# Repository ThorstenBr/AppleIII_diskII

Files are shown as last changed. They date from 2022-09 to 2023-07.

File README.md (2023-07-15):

# Apple III to disk II / FloppyEmu Adapter
This project decribes how to build an adapter connecting an Apple III to a [FloppyEmu from Big Mess of Wires](https://www.bigmessowires.com/floppy-emu/) - an SD-card based disk drive emulator.
Alternatively, the adapter can also be used to connect the Apple III to an original Apple **Disk II** drive (yes, Disk II, not Disk III).
The adapter works with either the internal or external floppy port of the Apple III.

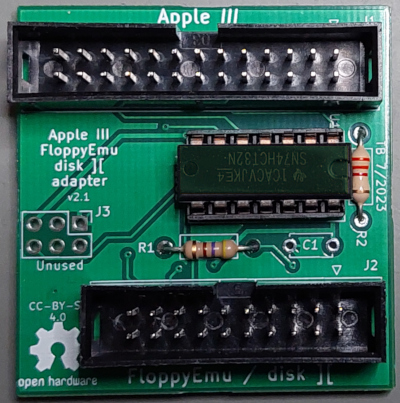
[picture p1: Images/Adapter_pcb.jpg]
Apple III FloppyEmu adapter PCB


As a bonus I also added a design file for a 3D-printed slim enclosure:

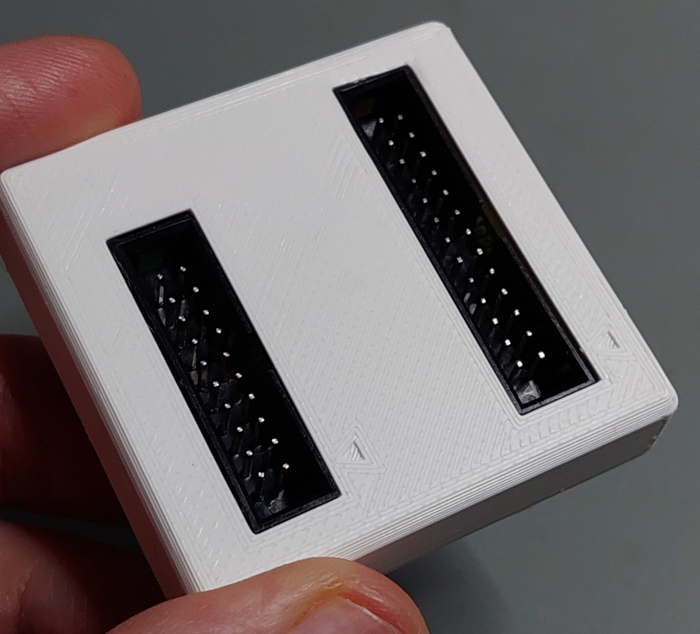
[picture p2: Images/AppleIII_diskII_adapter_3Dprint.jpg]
Apple III to Disk II adapter: 3D print


## License
This project is released under the "Creative Commons Attribution 4.0 International Public License". See [LICENSE](LICENSE).

## Description
It doesn't take much to connect a FloppyEmu to an Apple III. The disk drive interface of the Apple III is very similar to the Apple II - with most signals being completely identical. The Apple III, however, has a few extra signals and features, hence it uses a wider 26pin connector, instead of the 20pin connector of the Apple II. Most extra pins are not required for normal operation.

A few people have made the connection between Apple III and FloppyEmu/DiskII with a simple ribbon cable: using a 26pin IDC connector at one end, and a 20pin IDC connector (stripping the top 6 wires) at the other end. That did mostly work (if you don't mess up, reverse the connectors or strip wires from the wrong side, that is...). You can find more on this in [Steve's (BMOW) blog post](https://www.bigmessowires.com/2017/01/25/floppy-emu-on-the-apple-iii/).

**However**, such a simple 26pin to 20pin cable is not to be recommended - and it will not always work. For proper operation, one of the additional signals also has to be considered (see the "errata" section below, if you are interested in the details).

This adapter uses a cheap logic IC (74LS32) to properly decode the Apple /// drive enable signals and provide a signal to FloppyEmu or disk II. When connected to a FloppyEmu, the adapter also supports its "dual drive emulation" feature, where it emulates two separate disk drives.

The adapter can be connected to the Apple III disk port (internal or external port) and provides a standard 20pin connector, which can be used directly with the original FloppyEmu/Disk II cables.

### Using the Apple III external floppy port
You can connect the adapter to the external floppy port at the rear of your Apple III.

* **Disk II**: When using the external floppy port, the connected disk II drive acts as the system's "drive #2" (".D2", which confusingly is sometimes also refered to as "**external** drive #1").
* **FloppyEmu**: When connecting a FloppyEmu, you can enable its dual drive support. In this case your FloppyEmu will emulate the system "drive #2" and "drive #3" (".D2" and ".D3" - which are sometimes also called "**external** drives #1 and #2"). So, including the internal drive, you then have three floppy drives connected to your Apple III.

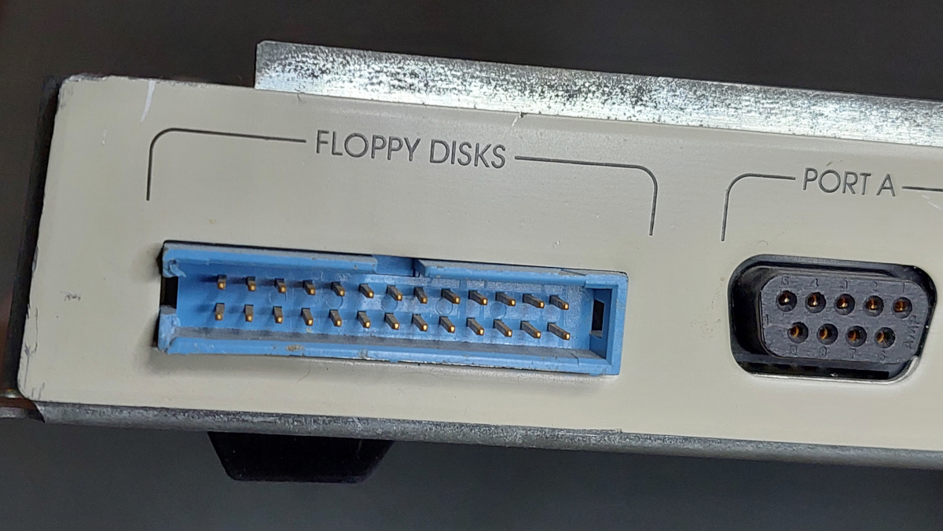
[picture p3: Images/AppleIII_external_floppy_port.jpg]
Apple III external floppy port


### Using the Apple III internal floppy port
The internal port connects the boot drive (system drive #1).
You can simply unplug the installed ribbon cable from the internal drive and plug it to the adapter's Apple III port.
No extra cable is required.

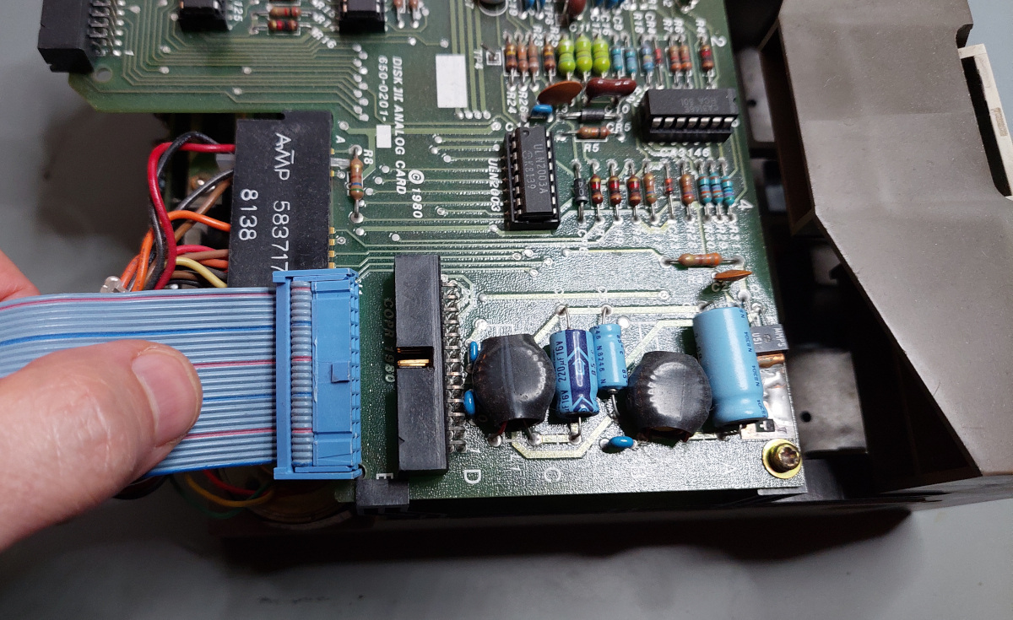
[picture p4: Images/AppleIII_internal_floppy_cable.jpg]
Apple III internal floppy cable

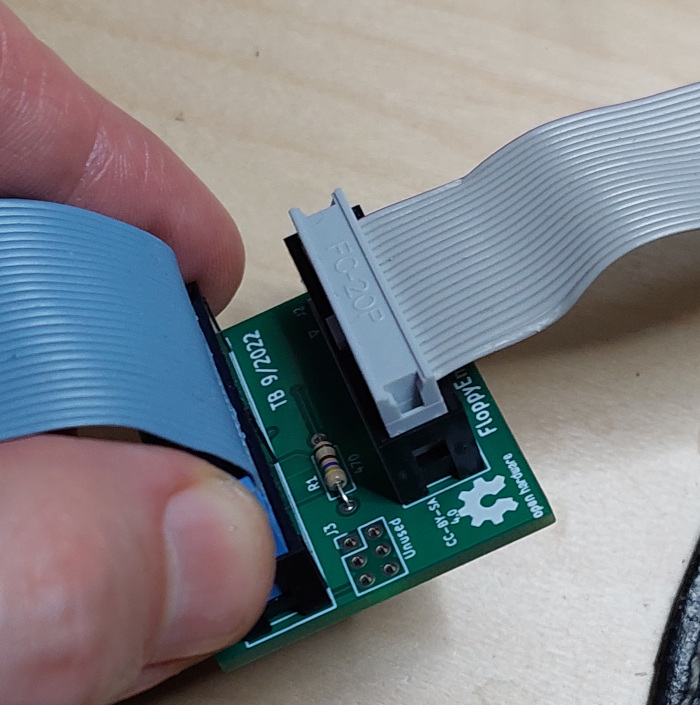
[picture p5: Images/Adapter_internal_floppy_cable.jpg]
Apple III internal floppy cable


When using the internal Apple III floppy port, the connected drive acts as drive #1 (".D1", boot drive).
The internal port does not support the signals for the external drives, however.
So, unfortunately you cannot make use of FloppyEmu's dual drive support to also emulate drive #2, when using the internal connector.

If you connect a new cable to the mainboard: the internal port is located on the mainboard right next to the external port:

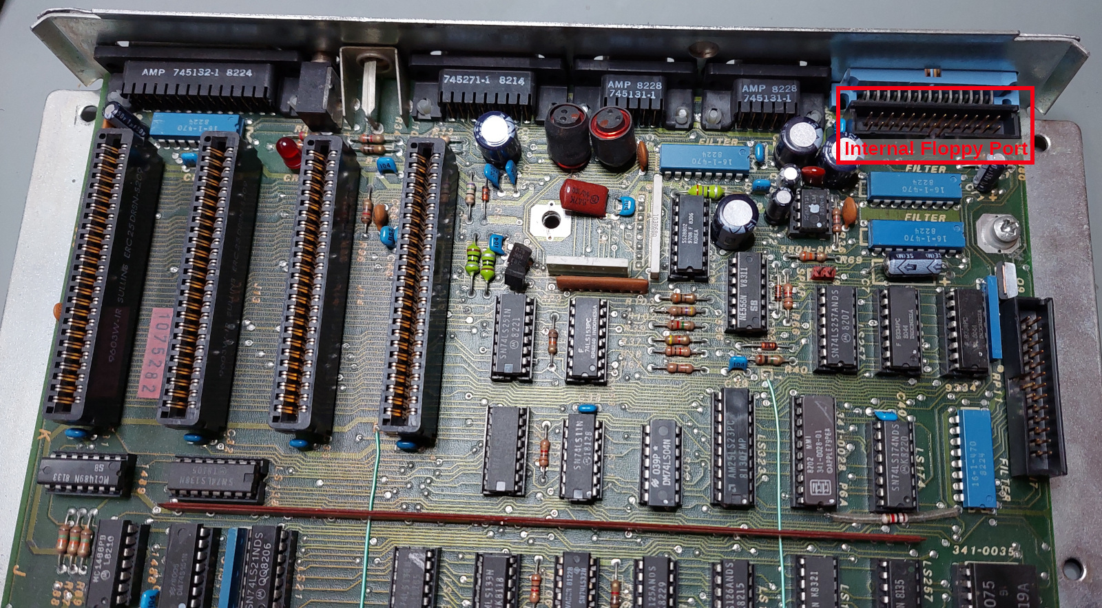
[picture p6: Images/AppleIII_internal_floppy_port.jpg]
Apple III internal floppy cable


## Parts List
Parts list for the completed PCB:
* 1x 20pin box header
* 1x 26pin box header
* 1x 14pin DIP socket (recommended)
* 1x IC SN74LS32 "OR-Gate" (74HCT32 also works but requires the optional 3K3 resistors)
* 1x 470 Ohm resistor
* 2x 3.3K Ohm resistors (optional/recommended)
* PCB (see Gerber files below)

<!--
![Adapter parts list](Images/Adapter_parts_list.jpg)
-->

Additionally, if you wanted to use Apple III's external floppy port, you may need a short 26pin ribbon cable with appropriate IDC sockets.
* 2x 26-pin IDC socket (with strain relief)
* 1x 26pin ribbon cable (a few inches/centimers are enough)

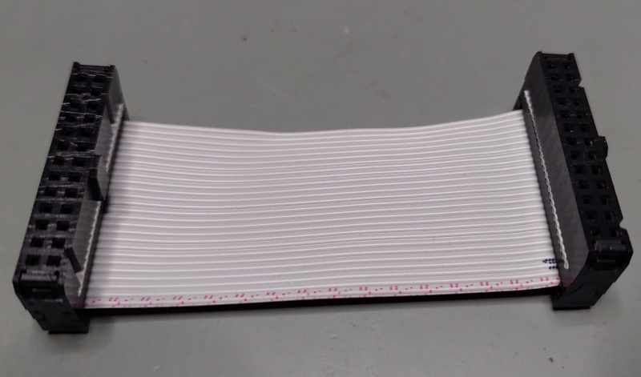
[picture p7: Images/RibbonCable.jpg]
Short 26wire ribbon cable


A very short ribbon cable will be enough for the external port (since your disk II/floppyEmu already comes with a long ribbon cable). Note, if you have any wider ribbon cables, you can easily reduce them to the appropriate wire count (so you would not need to shop an entire roll of new 26-write ribbon cable).

If you make your own ribbon cable: **MAKE SURE THE IDC SOCKETS ARE ORIENTED CONSISTENTLY!** Do not flip or reverse the orientation of the connectors (place them on the same side of the ribbon cable and with the notch facing the same direction).

For the internal floppy port you can reuse the existing floppy cable of your Apple III (unplug the internal floppy and plug the cable into the adapter instead).

I ordered parts from my usual German electronics online shop for less than a buck. Add a few bucks if you need a new ribbon cable ([Shopping List at Reichelt.de](https://www.reichelt.de/my/1980987?LANGUAGE=EN)).
I created a public shopping list containing all the parts. All parts are extremely common and will be available for a long time.

## Gerber Files, Ordering a PCB
If you wished to directly order a PCB (PCBWay, JLCPCB etc) you could use the latest Gerber files from the [Gerber](Gerber/) directory. Just upload the ZIP file to your preferred PCB manufacturer and order the PCB. My PCBs were manufactured by JLCPCB (using the cheapest options, I got mine already after about 1.5 weeks for a few bucks/Euros).

## Soldering
Soldering is straight forward. Only simple through-hole components are used. All part numbers and component values are marked directly on the PCB.

**DOUBLE-CHECK THE PROPER ORIENTATION OF THE BOX HEADERS!**  
The notch for the box headers are clearly marked on the PCB.
Incorrect orientation of the box headers for the Apple III or FloppyEmu port will damage or destroy your Apple III and FloppyEmu/disk II drive - or both...

The capacitor (C1) was added on the PCB as a backup. It is not required (leave the slot unused).

Completed PCB with orientation of the box headers

### Soldering Options
There are three solder jumpers on the bottom side of the adapter:

* **JP1**: connects the "drive 2" signal to the 20-pin connector. This signal enables dual drive support of FloppyEmu. This signal cannot be used when connecting an original Apple disk II drive, though. Setting this jumper will not damage anything when a disk II drive was connected, since there is also a resistor protecting the pin. But it adds unnecessary load. So, it's recommended to only close JP1 when you connect a FloppyEmu (and intend to use the dual drive support). Otherwise leave this jumper open.
* **JP2, JP3**: These jumpers connect -12V and +12V to the 20pin floppy header. These voltage supplies are required for the Apple disk II drive. But they are not required by FloppyEmu. It's recommended to leave these jumpers open if you intend to only connect a FloppyEmu. But they have to be closed when you wanted to connect an original disk II drive.

Jumpers on the Apple III disk II adapter

## Installation
Make sure the Apple III is switched off. **Do not connect the adapter, the Disk II, or Floppy Emu while your machine is powered!**

* Connect the adapter to the external floppy port at the rear of your Apple III (26pin ribbon cable required). Alternatively, connect it to the internal floppy port: pull the 26pin ribbon cable from the internal disk drive and plug it into the adapter.
* Finally connect the FloppyEmu's ribbon cable to the adapter. The FloppyEmu cable has a keyed connector (with a notch), so it should only fit in correct orientation.

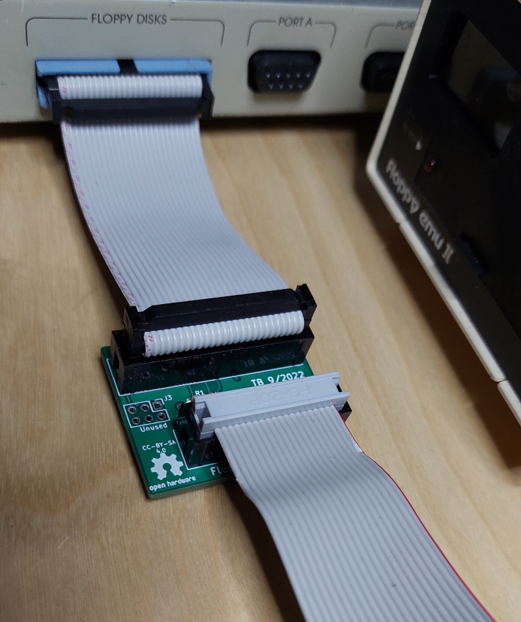
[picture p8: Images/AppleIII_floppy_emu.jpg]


* Alternatively, when you use the adapter to connect a Disk II drive, be extra careful: the Disk II connectors do not have a notch preventing incorrect orientation. You can easily plug them reversed, which will damage the drive and/or interface card. Pin 1 is marked with a little triangle on the PCB, on the 3D-printed enclosure - and also on the disk II connector.

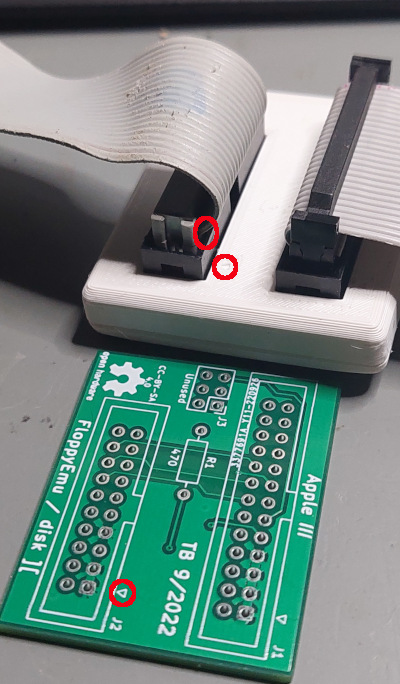
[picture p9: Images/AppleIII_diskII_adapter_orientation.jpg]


### Configuring the System for Three Drives

If you connect the FloppyEmu to the external connector, your system has three drives (the internal disk drive, and two external drives emulated by FloppyEmu).
However, with Apple's "SOS" operating system it is necessary to configure the system to make the third drive work (if your system was previously configured for two drives only).

Here are some hints on how to configure the Apple III:

* Use the "system utilities" disk.
* Enter the "System Configuration Program (SCP)".
* Select "Read a Driver File" to read ".D1/sos.driver" from your boot disk.
* Select "Change System Parameters".
* Set "Number of Disk III Drives" to 3 (or 4...).
* Select "Generate New System" and write the new configuration to ".D1/sos.driver" of your boot disk.

Yes, changing the configuration of the Apple III SOS is a bit inconvenient. :)
And make sure you have a backup of your boot disk, before you reconfigure anything...

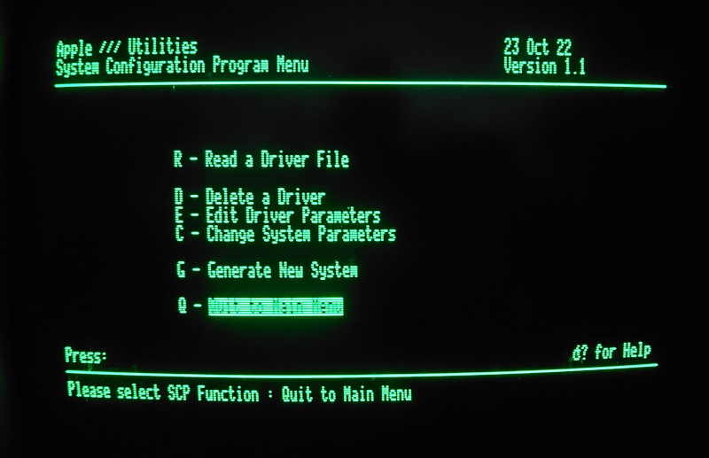
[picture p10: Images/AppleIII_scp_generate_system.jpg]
Apple SCP - generate new system


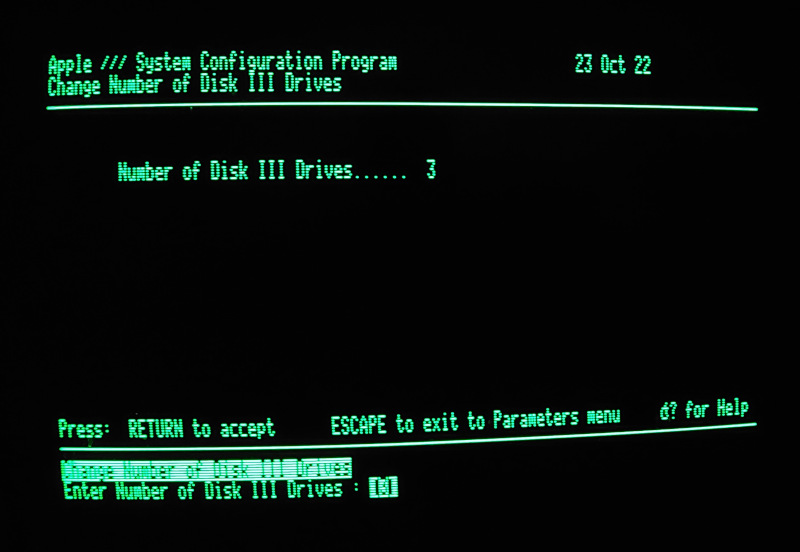
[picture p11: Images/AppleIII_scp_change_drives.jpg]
Apple SCP - change number of drives


## Errata / Technical Background ##
As described above, a number of people have made adapters by simply stripping away the 6 additional signals from the wider Apple III connector, and connect the 20 identical signals to a FloppyEmu/Disk II (in fact: the first version of the adapter in this project also followed this basic approach).

This will mostly work - when each drive is used individually. However, the Apple /// has a feature, which Apple IIs do not have: the Apple /// disk drive logic is able to keep the motor of the internal disk drive **and** one external disk drive spinning concurrently. This significantly speeds up the performance when copying data between internal and external disks - or when quickly reading files from both drives. The computer is no longer delayed by waiting for drive to reach their target rotation speed, when the drives keep spinning concurrently.

This feature is used on the Apple ///, for example, when using the "volume copy" feature of "SOS system utilties". While copying an entire disk, it keeps both drives spinning, while reading data from one disk and immediately writing it to the other. Disk copying is therefore much faster on the Apple III than on an Apple II (where the computer again and again needs to briefly wait while the two drives spin up and down).

This feature is implemented by Apple /// by keeping the *enable signals* for the internal and one of the external drives both enabled. These signals are at the same pin location as the respective signals of Apple II drives. However, on the Apple II it is forbidden for more than one drive to be enabled concurrently, since this would result in a conflict on the other shared communication signals. On the Apple II these signals meant "*enable motor **and** communication*". The Apple ///, however, has an additional signal on its 26pin port, which selects between internal and external communication. The disk enable signal on the Apple III only means "*enable motor*" - and therefore allows more than one drive to be enabled (spinning) at the same time. Still, communication always takes place with one drive only, when *additionally* an extra signal on the 26pin connector selects the internal port (or external port, respectively).

This adapter uses a simple 74LS32 logic IC (OR-gate), which properly considers all Apple III disk enable signals - and provides the correct signal to FloppyEmu (or disk II).

If you use CMOS logic devices (74HCT32) then the two pull-up resistors are required (they are recommended anyway).

## Schematics and KiCad Project
The [KiCad](KiCad/) folder contains the schematics and PCB project files, if you wished to adapt the design.

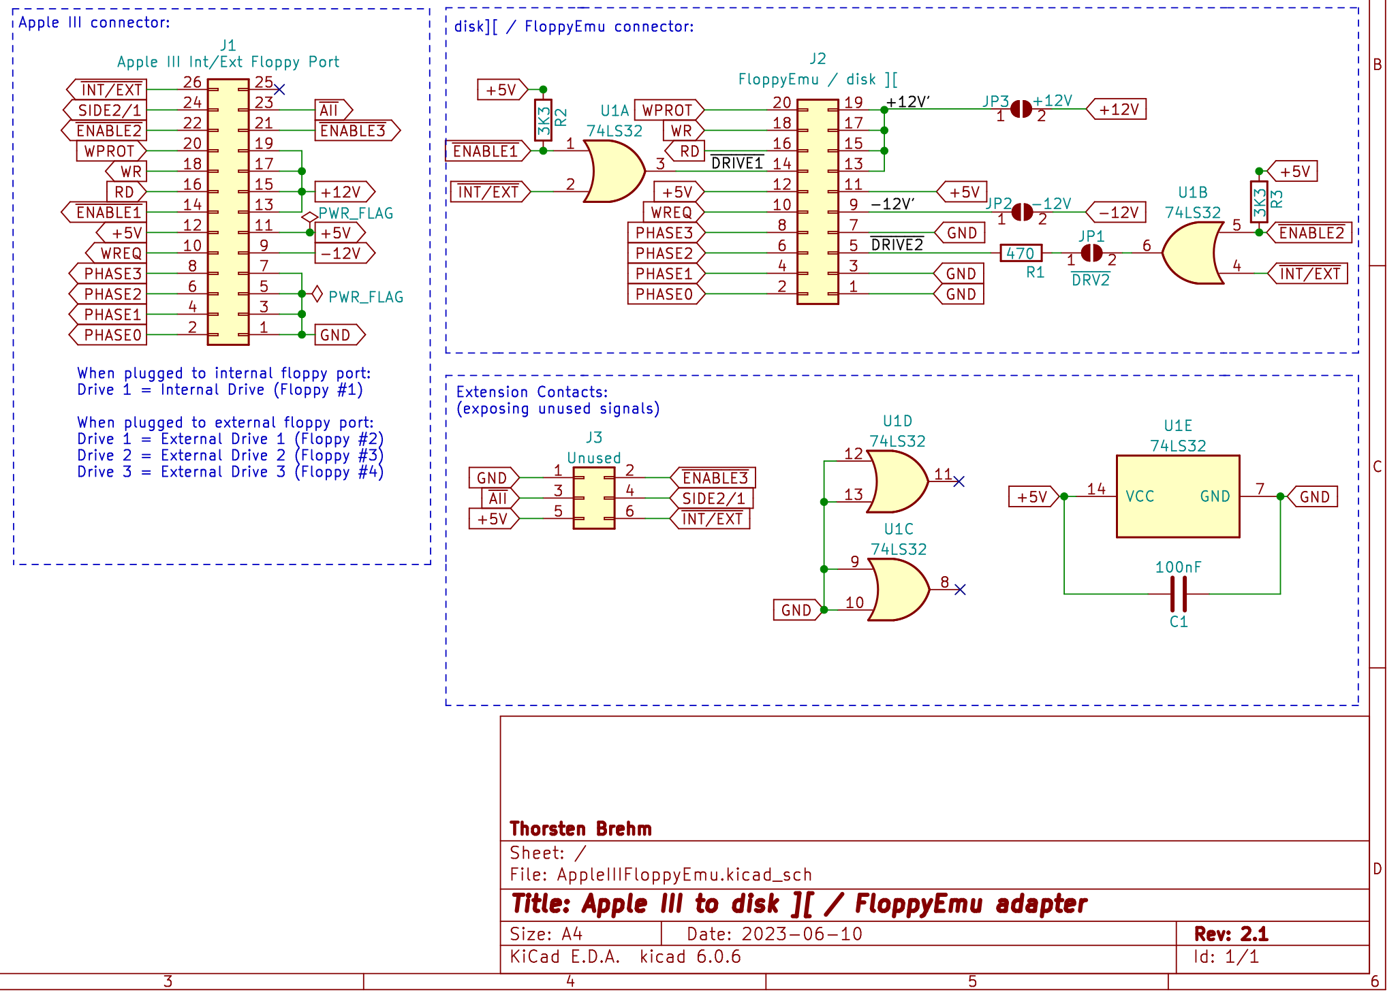
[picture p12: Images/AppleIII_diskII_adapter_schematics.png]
Schematics of the adapter


## Bonus: 3D-printed enclosure
As a bonus, I also added a design for a 3D-printed enclosure.
It's a neat and slim box which completely covers the PCB - eliminating any risk of creating short-circuits (remember the bottom side of the PCB has +/-12V and +5V voltage pins - so it's a good idea to cover them).
You'll find the 3D file (.stl) in the [/3DPrint](3DPrint/) folder.

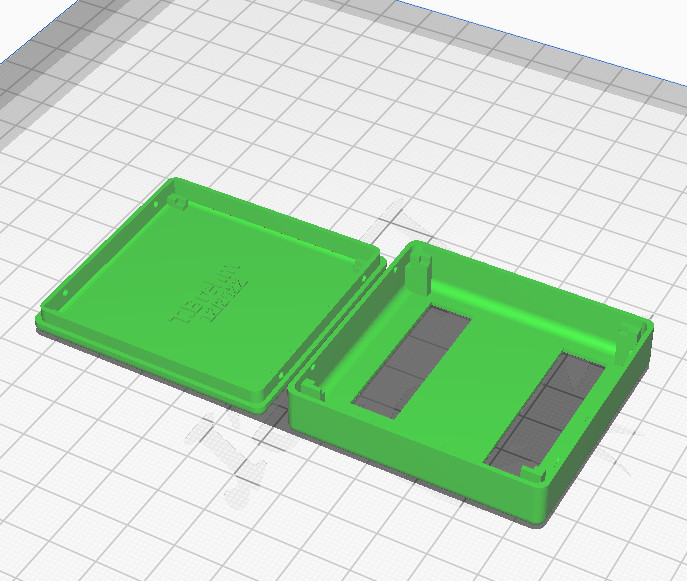
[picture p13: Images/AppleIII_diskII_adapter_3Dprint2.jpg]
Apple III to Disk II adapter: 3D print

Apple III to Disk II adapter: 3D print

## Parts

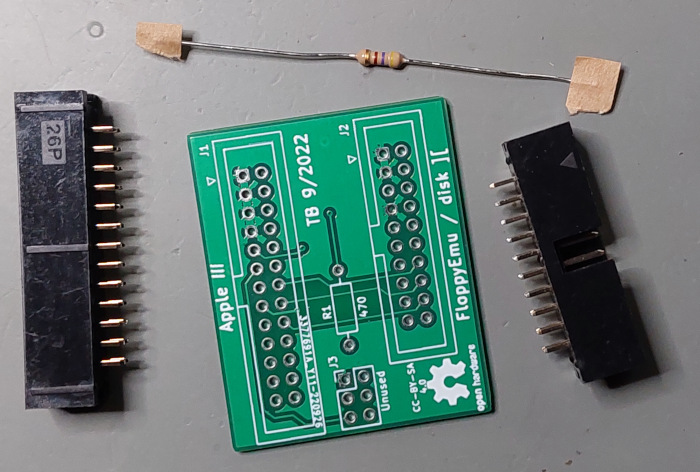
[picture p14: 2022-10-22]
Images/Adapter_parts_list.jpg

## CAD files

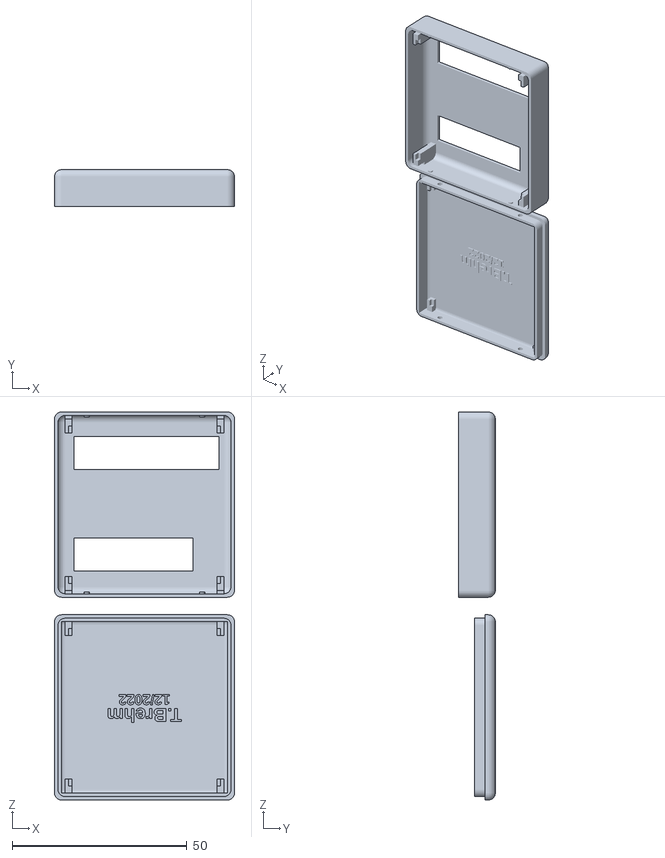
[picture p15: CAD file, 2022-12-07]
3DPrint/apple3_floppyemu.stl
51.5 x 10.5 x 111.0

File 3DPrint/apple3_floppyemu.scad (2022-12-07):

// Copyright 2022 Thorsten Brehm
// CC-BY-SA 4.0

// Which part do you want to see?
part = "bottom"; // [all:All,both:Both,bottom:Bottom,top:Top,prototype:Prototype,test:Test,lid:Lid]

// Add connector labels?
connector_labels = "no"; // [no:No,yes:Yes]


// Show PCB?
show_pcb = "no"; // [no:No,yes:Yes]

/* [Internals] */

// Radius of the corners
Box_Corner_Radius = 3.0; // [0: 10]

// Box skin width
SKIN = 1.0; // [1: 0.1: 5]

/* [Hidden] */

PcbY_BottomClearance = 1.0;

// PCB width
PcbX_Width = 43.5;
// PCB height
PcbY_Height = 2.5;
// PCB depth
PcbZ_Depth = 45;

// Width (X) of the box
BoxX_Width = PcbX_Width+6; // [10: 100]

// Height (Y) of the box
BoxY_Height = PcbY_BottomClearance+PcbY_Height+8; // [5: 100]

// Depth (Z) of the box
BoxZ_Depth = PcbZ_Depth+6; // [10: 200]

LedgeHeight = 3;
LedgeSkin   = 1;
LedgeOverlap = 1.5;

ConnectorDepth = 9.5;
ConnectorWidth1 = 34;
ConnectorWidth2 = 41.5;

// Quality
quality = "high"; // [low:Low,high:High]

include <baseLib.scad>

module logo(x,y,z)
{
 Font = "Liberation Sans:style=Bold";
 FontSize = 4;
 translate([x,y,z])
 {
   translate([0,0,2.2])
     rotate([90,0,180]) linear_extrude(height = 0.5) text("T.Brehm", font = Font, size = FontSize, halign="center", valign="center");
   translate([0,0,-2.2])
     rotate([90,0,180]) linear_extrude(height = 0.5) text("12/2022", font = Font, size = FontSize-1, halign="center", valign="center");
 }
}

module marker(x,y,z,h,txt)
{
 Font = "Liberation Sans";
 FontSize=3;
 translate([x,y,z])
 rotate([90,180,180])
 {
   linear_extrude(height = h) text(txt, font = Font, size = FontSize, halign="center");
 }
}

module label(x,y,z,h,txt,FontSize)
{
	Font = "Arial:style=Bold";
	translate([x,y,z])
	rotate([90,0,180])
	{
		linear_extrude(height = h) text(txt, font = Font, size = FontSize, halign="center");
	}
}

module pcb()
{
	translate([(BoxX_Width-PcbX_Width)/2,PcbY_BottomClearance,(BoxZ_Depth-PcbZ_Depth)/2])
	{
		cube([PcbX_Width, PcbY_Height, PcbZ_Depth]);
		translate([0,PcbY_Height,3.5])
		{
			translate([1.6,0,0])  cube([ConnectorWidth1, BoxY_Height*2, ConnectorDepth]);
			translate([1.6,0,29]) cube([ConnectorWidth2, BoxY_Height*2, ConnectorDepth]);
		}
	}
}

module boxOpenings()
{
	// circuit board
	pcb();
	marker(5+3,BoxY_Height+1-0.4,BoxZ_Depth-2.4,0.4, "▲");
	marker(5+3,BoxY_Height+1-0.4,20-0.4,0.4, "▲");

	if (connector_labels == "yes")
	{
		label(BoxX_Width/2,BoxY_Height+1-0.4,BoxZ_Depth-4.5,0.4, "APPLE III",3.5);
		label(ConnectorWidth1/2+5,BoxY_Height+1-0.4,3-0.4,  0.4, "D II  /  FEMU",3.5);
	}
}

module box(SkinWidth, XWidth, YHeight, ZDepth, CornerRadius)
{
	// main shell
	difference() {
		translate([-SkinWidth, -SkinWidth, -SkinWidth]) //roundedCube(0, XWidth+SkinWidth*2, YHeight+SkinWidth*2, ZDepth+SkinWidth*2, CornerRadius);
			rcube(size=[XWidth+SkinWidth*2, YHeight+SkinWidth*2, ZDepth+SkinWidth*2], radius=[2, 2, 2], center=false);
		if (SkinWidth>0)
			//roundedCube(0, XWidth, YHeight, ZDepth, CornerRadius);
			rcube(size=[XWidth, YHeight, ZDepth], radius=[2, 2, 2], center=false);
	}
}

module makeThing()
{
	XOfs = 2;
	YOfs = 5.5;
	translate([0,-2,0])
	difference()
	{
		union()
		{
			box(SKIN, BoxX_Width, BoxY_Height, BoxZ_Depth, Box_Corner_Radius);
			translate([XOfs,0,1]) cube([2,BoxY_Height,4]);
			translate([BoxX_Width-XOfs-2,0,1]) cube([2,BoxY_Height,4]);

			translate([XOfs,0,BoxZ_Depth-4-1]) cube([2,BoxY_Height,4]);
			translate([BoxX_Width-XOfs-2,0,BoxZ_Depth-4-1]) cube([2,BoxY_Height,4]);

			translate([XOfs,YOfs,0]) cube([2,BoxY_Height-YOfs,4]);
			translate([BoxX_Width-XOfs-2,YOfs,0]) cube([2,BoxY_Height-YOfs,4]);

			translate([XOfs,YOfs,BoxZ_Depth-4]) cube([2,BoxY_Height-YOfs,4]);
			translate([BoxX_Width-XOfs-2,YOfs,BoxZ_Depth-4]) cube([2,BoxY_Height-YOfs,4]);
		}
		boxOpenings();
	}
}

module makeLedge()
{
	translate([0, -LedgeOverlap, 0])
	difference()
	{
		cube([BoxX_Width, LedgeHeight+LedgeOverlap, BoxZ_Depth]);
		translate([LedgeSkin, 0, LedgeSkin]) cube([BoxX_Width-LedgeSkin*2, LedgeHeight+LedgeOverlap, BoxZ_Depth-LedgeSkin*2]);
	}
}

module lock(diameter, length)
{
	$fn=24;
	cylinder(r=diameter/2, length);
}

module locks(diameter, length)
{
	LockR = 1.5;
	translate([BoxX_Width/6,1.2,0]) lock(diameter, length);
	translate([BoxX_Width*5/6,1.2,0]) lock(diameter, length);
	translate([BoxX_Width/6,1.2,BoxZ_Depth-length]) lock(diameter, length);
	translate([BoxX_Width*5/6,1.2,BoxZ_Depth-length]) lock(diameter, length);
}

module makeTop()
{
	intersection()
	{
		makeThing();
		translate([-SKIN*2, 0, -SKIN*2]) cube([BoxX_Width+SKIN*4, BoxY_Height+SKIN*2, BoxZ_Depth+SKIN*4]);
	}
	locks(1.5, 0.5);
}

module makeBottom()
{
	difference()
	{
		union()
		{
			intersection()
			{
				makeThing();
				translate([-SKIN*2, -(BoxY_Height+SKIN*2), -SKIN*2]) cube([BoxX_Width+SKIN*4, BoxY_Height+SKIN*2, BoxZ_Depth+SKIN*4]);
			}
			makeLedge();
			logo(BoxX_Width/2,-2.1,BoxZ_Depth/2);
		}
		makeTop();
		locks(1.7, 1);
	}
}

module main() {
    if (part == "test")
    {
        boxOpenings();
    }
    else
    if (part == "top") {
        makeTop();
    }
    else
    if (part == "bottom") {
        makeBottom();
        if (show_pcb == "yes")
	        translate([0,-2,0]) pcb();
    }
    else
    if (part == "all") {
        makeTop();
	translate([0,-20,0]) makeBottom();
    } else
    if (part == "both") {
        makeTop();
	translate([0,7.5,-7]) rotate([180,0,0]) makeBottom();
    } else {
        // all
        makeThing();
    }
}

main();

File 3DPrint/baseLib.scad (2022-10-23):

// Copyright 2022 Thorsten Brehm
//

module torus(r1, r2)
{
    rotate_extrude(convexity = 10)
		translate([r2 + r1, 0, 0])
			circle(r=r2);
}

module round_cylinder(fillet, r, h)
{
	for(z=[fillet, h-fillet])
		translate([0,0,-z]) torus(r-2*fillet, fillet);
	cylinder(r=r-fillet, h);
	translate([0,0,fillet]) cylinder(r=r, h=h-2*fillet);
}

// Make a rectangle with rounded corners of given radius.
// The maximum outer dimensions exactly match the given width/height.
module roundedCube(Width, Height, Depth, CornerRadius)
{
	$fn=36;
	union()
	{
		for (x=[0,Width-CornerRadius*2])
		for (y=[0,Height-CornerRadius*2])
			translate([x+CornerRadius, y+CornerRadius, 0]) cylinder(r=CornerRadius, h=Depth);
		translate([CornerRadius,0,0]) cube([Width - 2*CornerRadius, Height, Depth]);
		translate([0,CornerRadius,0]) cube([Width, Height - 2*CornerRadius, Depth]);
	}
}

module cylinderLedge(r, length)
{
	$fn=36;
	translate([0, 0, -length/2])
	intersection()
	{
		cylinder(r=r, length);
		cube([r, r, length]);
	}
}

module rcube(size=[30, 20, 10], radius=[3, 2, 1], center=true)
{
	hull() {
        translate( center ? [0,0,0] : size/2 ) {
            cube(size-2*radius+[2*radius[0],0,0],center=true);
            cube(size-2*radius+[0,2*radius[1],0],center=true);
            cube(size-2*radius+[0,0,2*radius[2]],center=true);
 
            for(x = [-0.5,0.5], y = [-0.5,0.5], z = [-0.5,0.5])
                translate([x * ( size[0] - 2*radius[0]),
                           y * ( size[1] - 2*radius[1]),
                           z * ( size[2] - 2*radius[2])])
                    scale([radius[0], radius[1], radius[2]])
                        if (quality == "high") sphere(1.0,$fn=4*4*2); else sphere(1.0,$fn=4);
        }
    }
}

module hole(diameter, depth)
{
	$fn = 36;
	cylinder(r=diameter/2, h=depth);
}

module wall(width, height, WallThickness)
{
        translate([-width/2,-WallThickness/2,-height]) cube([width, WallThickness, height]);
}

module prism(l, w, h)
{
	polyhedron(
               points=[[0,0,0], [l,0,0], [l,w,0], [0,w,0], [0,w,h], [l,w,h]],
               faces=[[0,1,2,3],[5,4,3,2],[0,4,5,1],[0,3,4],[5,2,1]]
               );
}
	   
module post(height, diameter, post_fillet_r, screw_hole_diameter, screw_hole_depth)
{
	$fn = 36;
    difference() {
      union() {
        cylinder(r=diameter/2, h=height);
        difference() {
                cylinder(r=diameter/2 + post_fillet_r, h=post_fillet_r);
                translate([0,0,post_fillet_r]) torus(diameter/2, post_fillet_r*1.1);
        }
      }
      if (screw_hole_diameter>0)
      {
          translate([0,0,height-screw_hole_depth])
          hole(screw_hole_diameter, screw_hole_depth);
      }
    }
}

module screwPost(ZDepth, PostDiameter, ScrewDiameter, ScrewHoleDepth, FilletR)
{
    if (PostDiameter>0.0)
	post(ZDepth, PostDiameter, FilletR, ScrewDiameter, ScrewHoleDepth);
}


module outerBox(SkinWidth, XWidth, YHeight, ZDepth, CornerRadius)
{
	translate([-SkinWidth, -SkinWidth, 0]) roundedCube(XWidth+SkinWidth*2, YHeight+SkinWidth*2, ZDepth, CornerRadius);
}

module box(SkinWidth, XWidth, YHeight, ZDepth, CornerRadius)
{
	// main shell
	difference() {
		outerBox(SkinWidth, XWidth, YHeight, ZDepth, CornerRadius);
			//rcube(size=[XWidth+SkinWidth*2, YHeight+SkinWidth*2, ZDepth+SkinWidth*2], radius=[2, 2, 2], center=false);
		if (SkinWidth>0)
			roundedCube(XWidth, YHeight, ZDepth, CornerRadius);
			//rcube(size=[XWidth, YHeight, ZDepth], radius=[2, 2, 2], center=false);
	}
}

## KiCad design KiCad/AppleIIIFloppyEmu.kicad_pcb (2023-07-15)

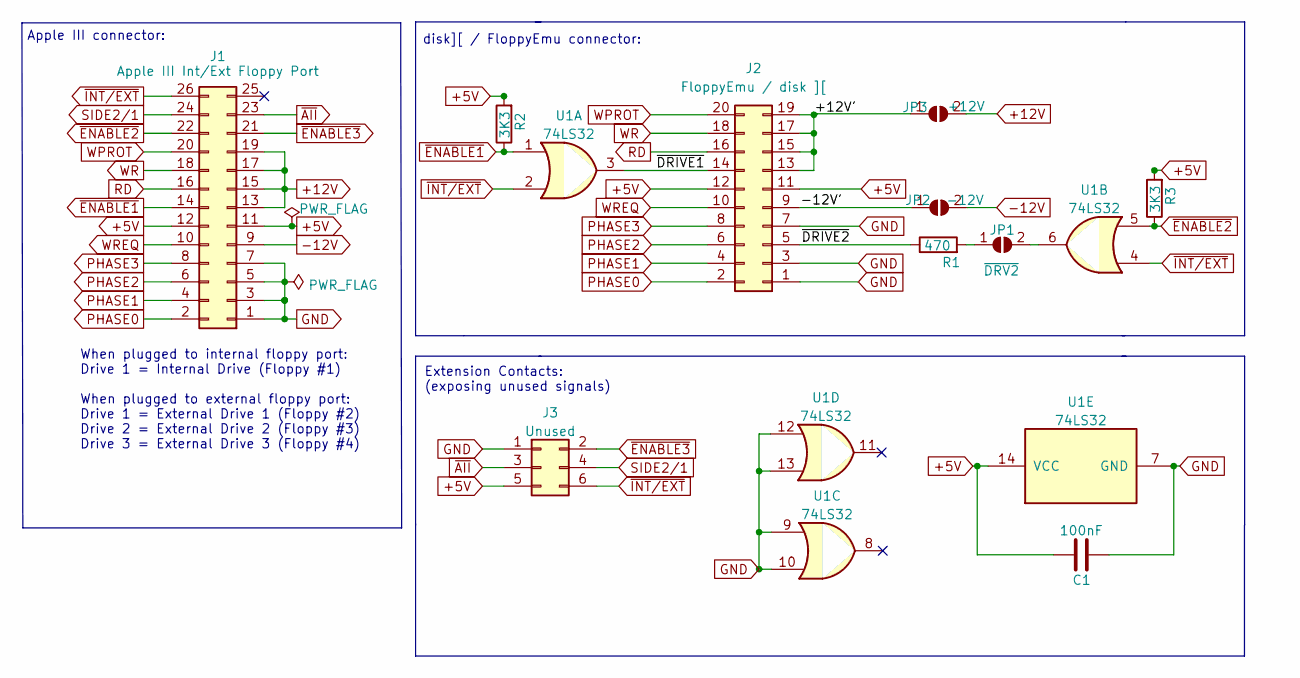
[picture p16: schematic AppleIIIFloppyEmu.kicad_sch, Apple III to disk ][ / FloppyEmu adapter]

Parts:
C1: 100nF; C_Disc_D4.7mm_W2.5mm_P5.00mm
J1: Apple III Int/Ext Floppy Port; IDC-Header_2x13_P2.54mm_Vertical
J2: FloppyEmu / disk ][; IDC-Header_2x10_P2.54mm_Vertical
J3: Unused; PinHeader_2x03_P2.54mm_Vertical
JP1: ~{DRV2}; SolderJumper-2_P1.3mm_Open_RoundedPad1.0x1.5mm
JP2: -12V; SolderJumper-2_P1.3mm_Open_RoundedPad1.0x1.5mm
JP3: +12V; SolderJumper-2_P1.3mm_Open_RoundedPad1.0x1.5mm
R1: 470; R_Axial_DIN0207_L6.3mm_D2.5mm_P10.16mm_Horizontal
R2, R3: 3K3; R_Axial_DIN0207_L6.3mm_D2.5mm_P10.16mm_Horizontal
U1: 74LS32; DIP-14_W7.62mm_Socket_LongPads

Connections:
+5V: C1.1, J1.11, J1.12, J2.11, J2.12, J3.5, R2.2, R3.2, U1.14 (VCC)
+12V: J1.13, J1.15, J1.17, J1.19, JP3.2 (B)
-12V: J1.9, JP2.2 (B)
/+12V': J2.13, J2.15, J2.17, J2.19, JP3.1 (A)
/-12V': J2.9, JP2.1 (A)
/~DRIVE1: J2.14, U1.3
/~DRIVE2: J2.5, R1.1
GND: C1.2, J1.1, J1.3, J1.5, J1.7, J2.1, J2.3, J2.7, J3.1, U1.7 (GND), U1.9, U1.10, U1.12, U1.13
unnamed: JP1.1 (A), R1.2
unnamed: JP1.2 (B), U1.6
PHASE0: J1.2, J2.2
PHASE1: J1.4, J2.4
PHASE2: J1.6, J2.6
PHASE3: J1.8, J2.8
RD: J1.16, J2.16
SIDE2/1: J1.24, J3.4
WPROT: J1.20, J2.20
WR: J1.18, J2.18
WREQ: J1.10, J2.10
~AII: J1.23, J3.3
~ENABLE1: J1.14, R2.1, U1.1
~ENABLE2: J1.22, R3.1, U1.5
~ENABLE3: J1.21, J3.2
~INT/EXT: J1.26, J3.6, U1.2, U1.4

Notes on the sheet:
Extension Contacts: (exposing unused signals)
When plugged to internal floppy port: Drive 1 = Internal Drive (Floppy #1) When plugged to external floppy port: Drive 1 = External Drive 1 (Floppy #2) Drive 2 = External Drive 2 (Floppy #3) Drive 3 = External Drive 3 (Floppy #4)
Apple III connector:
disk][ / FloppyEmu connector:

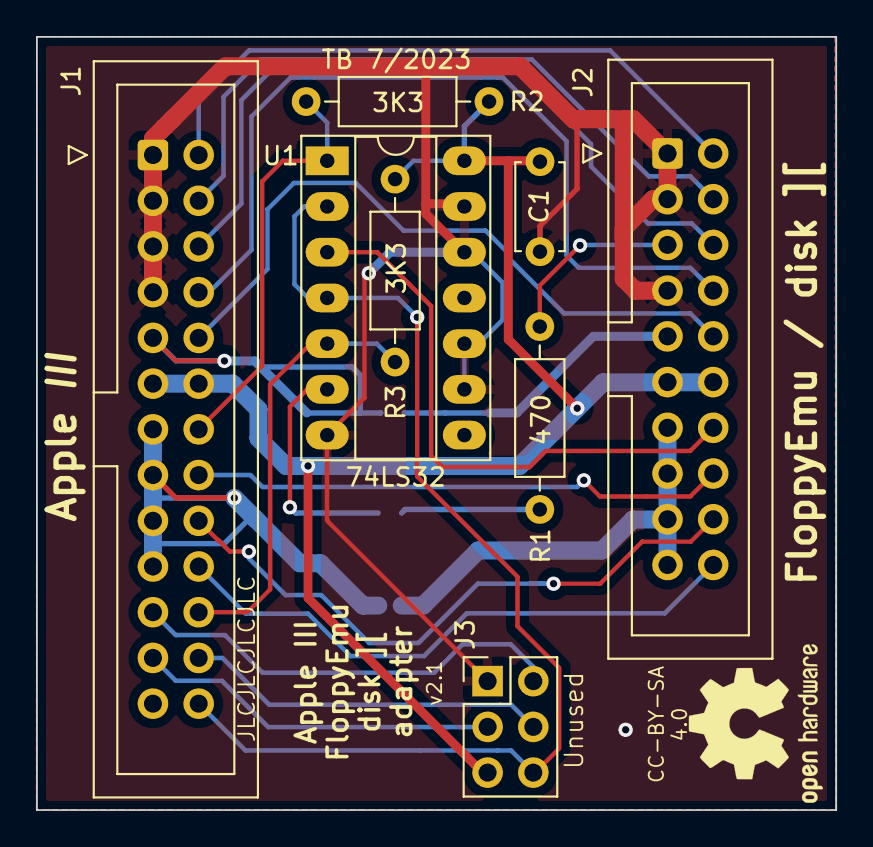
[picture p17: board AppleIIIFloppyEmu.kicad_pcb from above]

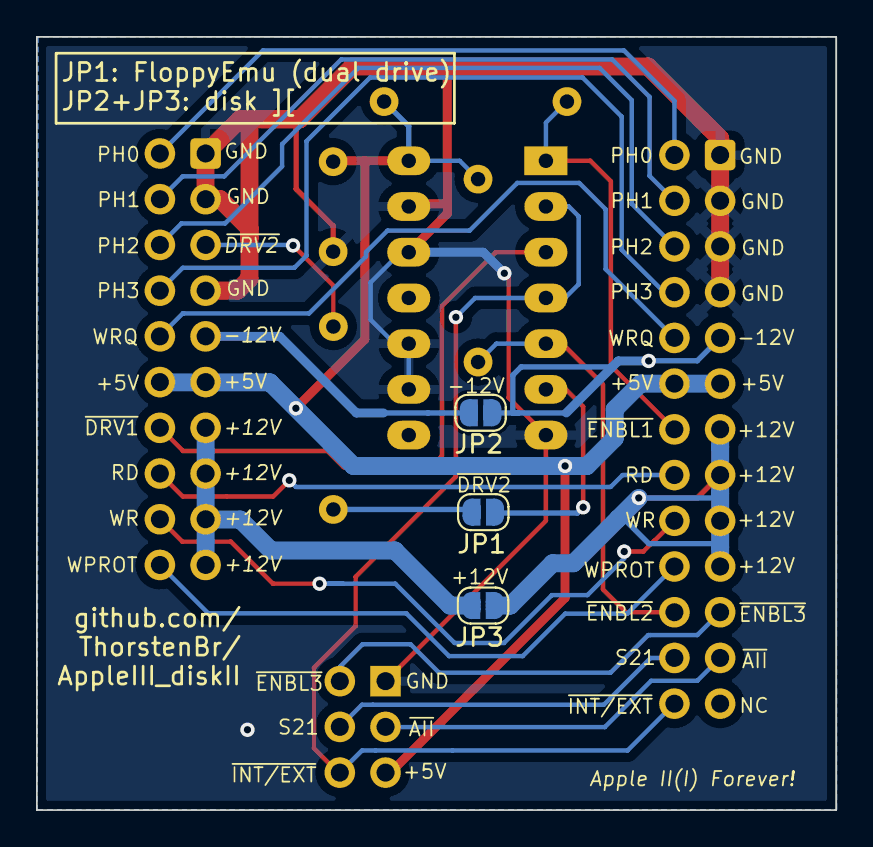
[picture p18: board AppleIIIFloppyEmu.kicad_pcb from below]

Board: 2 copper layers, 44.4 x 43.0 mm, 11 parts (3 on the bottom side), 24 nets.

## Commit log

2022-09-25 Initial revision: v1.0
    [AppleIIIFloppyEmu.kicad_pcb, AppleIIIFloppyEmu.kicad_sch]
2022-09-25 Updated README. Update to rev 1.1.
    [AppleIIIFloppyEmu.kicad_pcb, AppleIIIFloppyEmu.kicad_sch]
2022-10-22 Added photos of completed PCB
2022-10-23 Added design files for 3D-printed enclosure
    [apple3_floppyemu.scad, apple3_floppyemu.stl, baseLib.scad]
2022-10-23 Dropped the v1.0 Gerber file.
2022-10-24 Added another photo of the 3D print.
    [apple3_floppyemu.scad, apple3_floppyemu.stl]
2022-11-06 Updated to v2.0: properly handle Apple /// Disk logic when SOS keeps the internal and one external drive spinning concurrently, while alternating the access to both drives. SOS uses this feature when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
    [AppleIIIFloppyEmu.kicad_pcb, AppleIIIFloppyEmu.kicad_sch]
2022-12-05 Updated with photo of latest PCB revision.
2022-12-07 Adapted 3D printed enclosure to latest PCB design.
    [apple3_floppyemu.scad, apple3_floppyemu.stl]
2023-07-15 Added optional pull-ups to ENBL1+2 to allow use of 74HCT32 ICs. The pull-ups (R2+R3) are not strictly required for 74LS32 ICs (but recommended anyway). R3 may be soldered on the top side, before sold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
    [AppleIIIFloppyEmu.kicad_pcb, AppleIIIFloppyEmu.kicad_sch]
